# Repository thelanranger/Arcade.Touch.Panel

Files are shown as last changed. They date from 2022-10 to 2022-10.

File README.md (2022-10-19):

# Arcade.Touch.Panel
Capacative Touch Panel using custom PCB and Arduino Leo

int pins are mapped to custom PCB in eagle files. 
Buttons are VCClite capacative touch LCD buttons:
https://vcclite.com/product/csms15cic04/

I specifically used White which did not need SMD resistors and run fine off of USB power (though they are VERY bright).

LEDTimer = 100000;  Can be adjusted to set how long until 'latched' buttons auto off their lights. Example: If you press a button and it is set to 'non latching' the light would blink on touch, but then be in 'always off'. If it was 'latched' (such as mute) the light will remain lit once pressed until it is pressed again OR until LEDTimer ms have passed. Any lights in the 'latched' state would return to their state position on the next button touch.

switch (Bindex) defines the 8 buttons. This sends keystrokes to the system as if the Leonardo was a simple keyboard. The sample file is setup with hotkeys that map to the associated AutoHotKey file to perform the designated actions. 

Example of unlatched press (case 0):
    3 keys are pressed in sequence using Keyboard.press(); then all released using Keyboard.releaseAll();. The light is 'blinked' with a pin write HIGH, delay, and pin write LOW. This sends the sequence of keys then blinks the light. No data is retained and everything is ready for the next loop.

Example of a latched press (case 1):
    lastLEDState[Bindex] is verified. If 'unlatched state' is stored for this button number then we perform the keypress and switch the state from 0 to 1. An immediate exit will allow the cycleLEDs() routine to update turn on the LED and return for the next press. If the reverse is true we can pass the same set of keys again, or an alternate set (in this case we're passing Play [CTRL+SHIFT+G], on latch, then Stop [CTRL+SHIFT+D] on unlatch) and changing the state to off.

This should allow you to perform almost any task! You can even double your buttons with a latching 'shift' button! Just update your .ahk file to match your keystrokes and go nuts.

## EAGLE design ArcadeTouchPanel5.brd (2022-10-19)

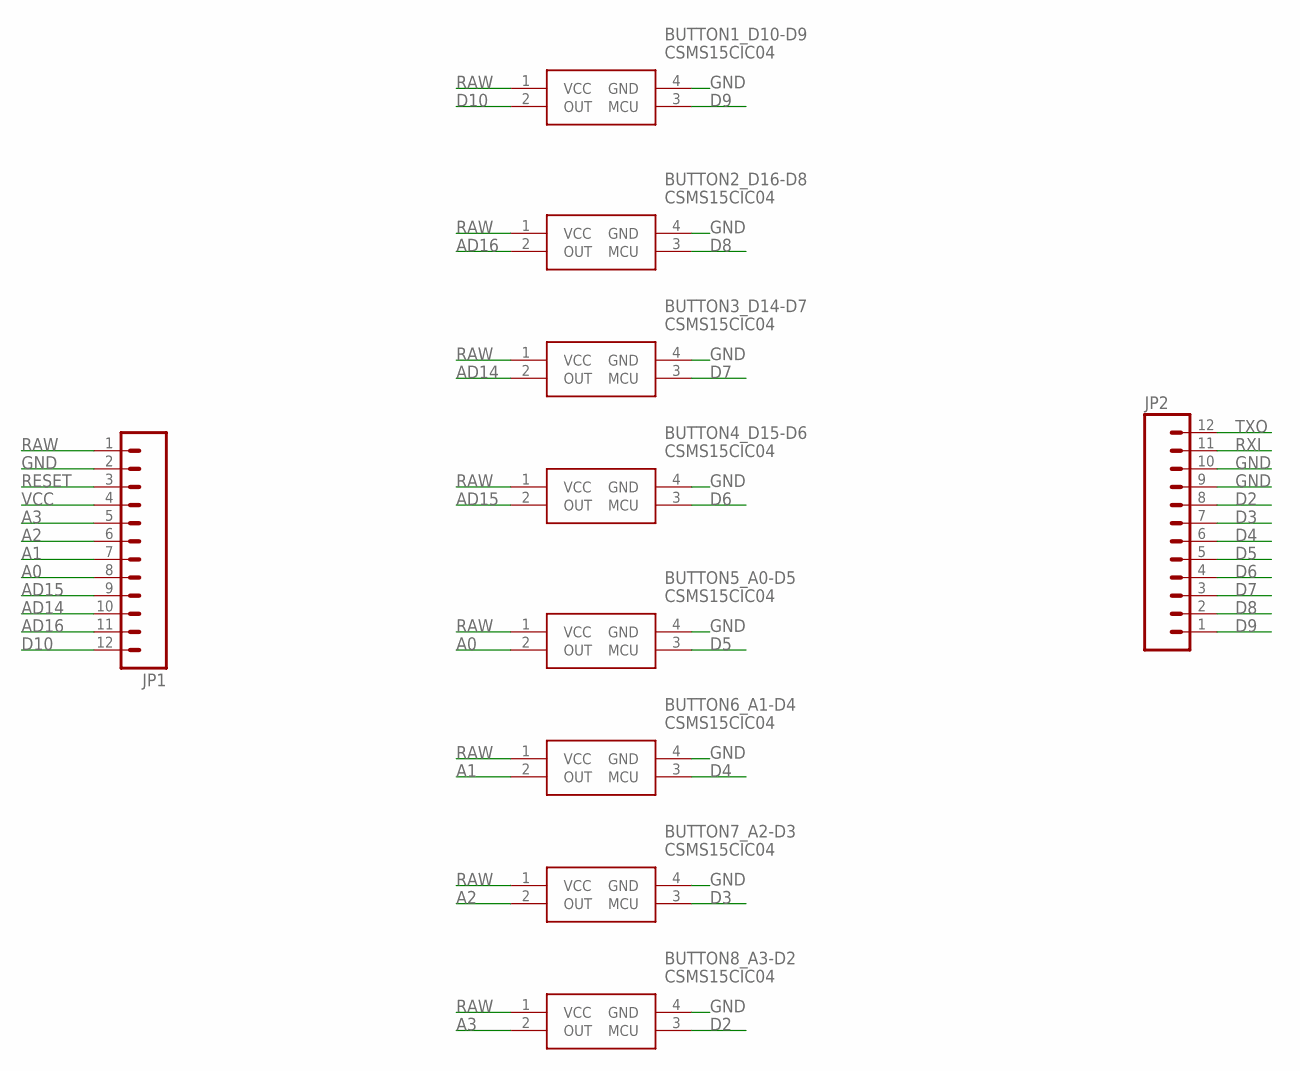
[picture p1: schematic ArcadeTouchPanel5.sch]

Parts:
BUTTON1_D10-D9, BUTTON2_D16-D8, BUTTON3_D14-D7, BUTTON4_D15-D6, BUTTON5_A0-D5, BUTTON6_A1-D4, BUTTON7_A2-D3, BUTTON8_A3-D2: CSMS15CIC04
JP1, JP2: M12PTH; 1X12

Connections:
A0: BUTTON5_A0-D5.2 (OUT), JP1.8
A1: BUTTON6_A1-D4.2 (OUT), JP1.7
A2: BUTTON7_A2-D3.2 (OUT), JP1.6
A3: BUTTON8_A3-D2.2 (OUT), JP1.5
AD14: BUTTON3_D14-D7.2 (OUT), JP1.10
AD15: BUTTON4_D15-D6.2 (OUT), JP1.9
AD16: BUTTON2_D16-D8.2 (OUT), JP1.11
D2: BUTTON8_A3-D2.3 (MCU), JP2.8
D3: BUTTON7_A2-D3.3 (MCU), JP2.7
D4: BUTTON6_A1-D4.3 (MCU), JP2.6
D5: BUTTON5_A0-D5.3 (MCU), JP2.5
D6: BUTTON4_D15-D6.3 (MCU), JP2.4
D7: BUTTON3_D14-D7.3 (MCU), JP2.3
D8: BUTTON2_D16-D8.3 (MCU), JP2.2
D9: BUTTON1_D10-D9.3 (MCU), JP2.1
D10: BUTTON1_D10-D9.2 (OUT), JP1.12
GND: BUTTON1_D10-D9.4 (GND), BUTTON2_D16-D8.4 (GND), BUTTON3_D14-D7.4 (GND), BUTTON4_D15-D6.4 (GND), BUTTON5_A0-D5.4 (GND), BUTTON6_A1-D4.4 (GND), BUTTON7_A2-D3.4 (GND), BUTTON8_A3-D2.4 (GND), JP1.2, JP2.9, JP2.10
RAW: BUTTON1_D10-D9.1 (VCC), BUTTON2_D16-D8.1 (VCC), BUTTON3_D14-D7.1 (VCC), BUTTON4_D15-D6.1 (VCC), BUTTON5_A0-D5.1 (VCC), BUTTON6_A1-D4.1 (VCC), BUTTON7_A2-D3.1 (VCC), BUTTON8_A3-D2.1 (VCC), JP1.1
RESET: JP1.3
RXI: JP2.11
TXO: JP2.12
VCC: JP1.4

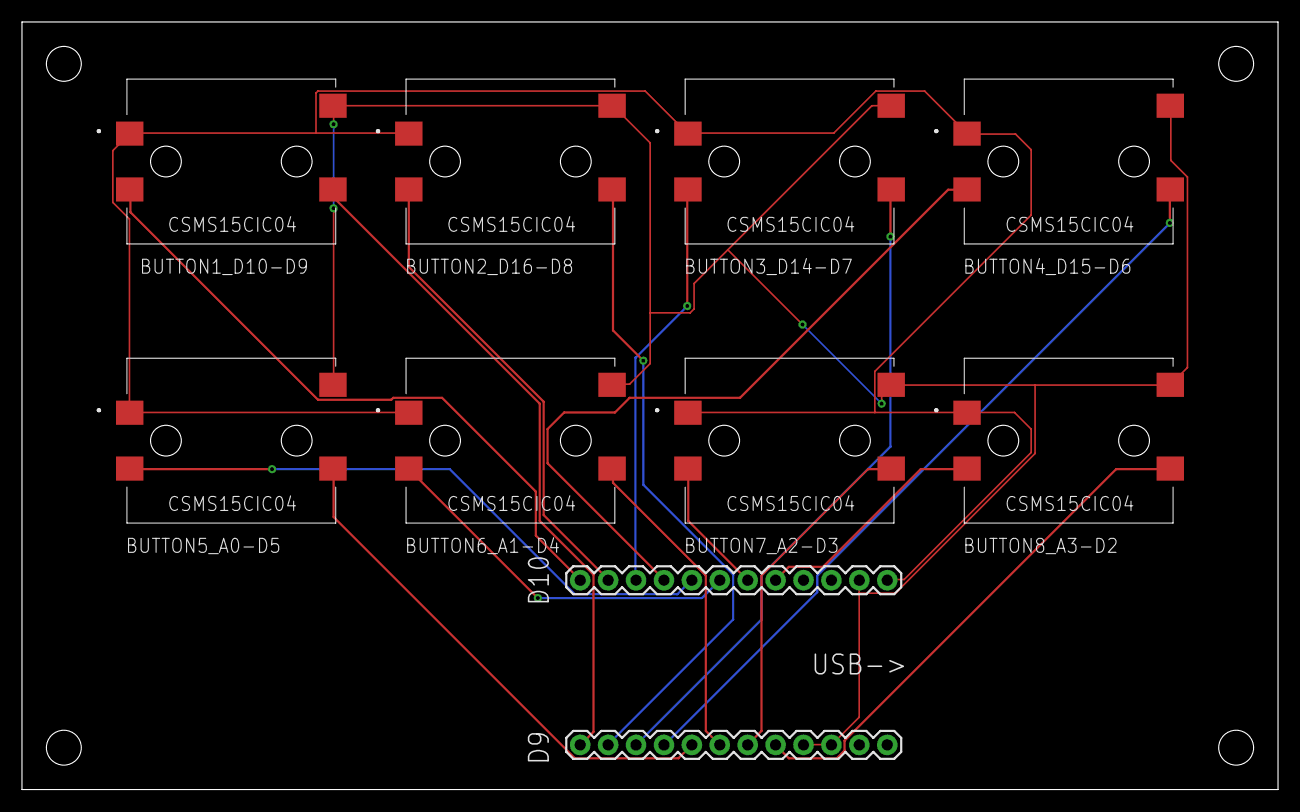
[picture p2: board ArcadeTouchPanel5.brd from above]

Board: 2 copper layers, 114.3 x 69.8 mm, 10 parts (0 on the bottom side), 18 nets.

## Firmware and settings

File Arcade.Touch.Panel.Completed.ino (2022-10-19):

#include "Keyboard.h"

// --Input Pins--
//const int startButton = 18;           //First Button Pin (Digital)
//const int startLED = 8;               //First LED Pin (Digital)
const int totalButtons = 8;             //Total Buttons
const int buttonPins[] = {10, 16, 14, 15, 18, 19, 20, 21};
const int LEDPins[] = {9, 8, 7, 6, 5, 4, 3, 2};
// --Input Pins--

const int Bsmoothing = 50;            // Repeat speed of keys
const int clickDelay = 150;           // Pause Between Clicks
const int long LEDTimer = 100000;           // Time until LEDs Auto Off
int Bsmoothingindex = 0;              // Index of button smoother
int currentButtonState = 0;           // Current Button State
int currentButtonTotal = 0;           // Smoothed State
int long currentLEDState = 0;              // Current LED State
int long currentLEDTime = 0;               // Current LED Time
int lastButtonState[totalButtons][Bsmoothing];    // Last state of the buttons - number of interations
int smoothedButtonState[totalButtons];// Current Button State after smoothing
int lastLEDState[totalButtons];       // Last state of the LEDs

void setup() {
  Serial.begin(9600);

  // --Initialize Button Pins--
  pinMode(0, INPUT_PULLUP); //-- Escape Key!--

  for (int initPinIndex = 0; initPinIndex < totalButtons; initPinIndex++)
  {
    pinMode(buttonPins[initPinIndex], INPUT_PULLUP);
  }
  // --Initialize Button Pins--

  // --Initialize LED Pins--
  for (int initPinIndex = 0; initPinIndex < totalButtons; initPinIndex++)
  {
    pinMode(LEDPins[initPinIndex], OUTPUT);
  }
  // --Initialize Button Pins--

  // --Button Array Init--
  for (int thisReading = 0; thisReading < totalButtons; thisReading++)
  {
    for (int thatReading = 0; thatReading < Bsmoothing; thatReading++)
    {
      lastButtonState[thisReading][thatReading] = 0;
    }
    lastLEDState[thisReading] = 0;
    smoothedButtonState[totalButtons] = 0;
  }
  // --Button Array Init--

  Keyboard.begin();

}

void loop() {
  // --Escape Key!--
  while (digitalRead(0) == LOW)
  {
    Keyboard.releaseAll();
    currentLEDTime = LEDTimer;
    delay(1000);
    Serial.print("Esc State: ");
    Serial.println(digitalRead(0));
  }
  // --Escape Key!--

  buttonPress();
  cycleLEDs();

  // --Read pin values for buttons--
  for (int Bindex = 0; Bindex < totalButtons; Bindex++)
  {
    currentButtonState = digitalRead(buttonPins[Bindex]);
    if (currentButtonState != lastButtonState[Bindex][Bsmoothingindex])
    {
      lastButtonState[Bindex][Bsmoothingindex] = currentButtonState;
    }
  }
  // --Read pin values for buttons--

  Bsmoothingindex++;
  if (Bsmoothingindex > Bsmoothing)
  {
    Bsmoothingindex = 0;
  }
}

void buttonPress()
{
  // --Iterate lastButtonState[][], total, average, populate smoothedButtonState[]--
  for (int Bindex = 0; Bindex < totalButtons; Bindex++)
  {
    currentButtonTotal = 0;

    for (int Sindex = 0; Sindex < Bsmoothing; Sindex++)
    {
      currentButtonTotal = currentButtonTotal + lastButtonState[Bindex][Sindex];
    }

    if ((currentButtonTotal / Bsmoothing) == 0)
    {
      smoothedButtonState[Bindex] = 0;
    }
    else
    {
      smoothedButtonState[Bindex] = 1;
    }
  }
  // --Iterate lastButtonState[][], total, average, populate smoothedButtonState[]--

  // --Iterate smoothedButtonState[], update lastLEDState[], send Keyboard.Press()--
  for (int Bindex = 0; Bindex < totalButtons; Bindex++)
  {
    if (smoothedButtonState[Bindex] == 1)
    {
      smoothedButtonState[Bindex] = 0;
      currentLEDTime = 0;                   //  Auto LED Off reset
      for (int Rindex = 0; Rindex < Bsmoothing; Rindex++)
      {
        lastButtonState[Bindex][Rindex] = 0;
      }
      switch (Bindex) {
        case 0:     // Winamp Previous  (CTRL+SHIFT+A)
          Keyboard.press(KEY_LEFT_CTRL);
          Keyboard.press(KEY_LEFT_SHIFT);
          Keyboard.press('A');
          Keyboard.releaseAll();
          digitalWrite(LEDPins[Bindex], HIGH);
          delay(clickDelay);
          digitalWrite(LEDPins[Bindex], LOW);
          delay(clickDelay);
          break;
        case 1:     // Winamp Play/Pause/Stop  (CTRL+SHIFT+G)/(CTRL+SHIFT+H)/(CTRL+SHIFT+D)
          if (lastLEDState[Bindex] == 0)
          {
            lastLEDState[Bindex] = 1;
            Keyboard.press(KEY_LEFT_CTRL);
            Keyboard.press(KEY_LEFT_SHIFT);
            Keyboard.press('G');
            Keyboard.releaseAll();
            //digitalWrite(LEDPins[Bindex], HIGH);
            delay(clickDelay);
            break;
          }
          if (lastLEDState[Bindex] == 1)
          {
            lastLEDState[Bindex] = 0;
            Keyboard.press(KEY_LEFT_CTRL);
            Keyboard.press(KEY_LEFT_SHIFT);
            Keyboard.press('D');
            Keyboard.releaseAll();
            //digitalWrite(LEDPins[Bindex], LOW);
            delay(clickDelay);
            break;
          }
          break;
        case 2:     // Winamp Next  (CTRL+SHIFT+F)
          Keyboard.press(KEY_LEFT_CTRL);
          Keyboard.press(KEY_LEFT_SHIFT);
          Keyboard.press('F');
          Keyboard.releaseAll();
          digitalWrite(LEDPins[Bindex], HIGH);
          delay(clickDelay);
          digitalWrite(LEDPins[Bindex], LOW);
          delay(clickDelay);
          break;
        case 3:     // Pending | Pause (P)
          //Keyboard.press(KEY_LEFT_CTRL);
          //Keyboard.press(KEY_LEFT_SHIFT);
          Keyboard.press('P');
          Keyboard.releaseAll();
          digitalWrite(LEDPins[Bindex], HIGH);
          delay(clickDelay);
          digitalWrite(LEDPins[Bindex], LOW);
          delay(clickDelay);
          break;
        case 4:     // Volume Down  (CTRL+SHIFT+-)
          Keyboard.press(KEY_LEFT_CTRL);
          Keyboard.press(KEY_LEFT_SHIFT);
          Keyboard.press('-');
          Keyboard.releaseAll();
          digitalWrite(LEDPins[Bindex], HIGH);
          delay(clickDelay);
          digitalWrite(LEDPins[Bindex], LOW);
          delay(clickDelay);
          break;
        case 5:     // Volume Up  (CTRL+SHIFT+=)
          delay(clickDelay);
          Keyboard.press(KEY_LEFT_CTRL);
          Keyboard.press(KEY_LEFT_SHIFT);
          Keyboard.press('=');
          Keyboard.releaseAll();
          digitalWrite(LEDPins[Bindex], HIGH);
          delay(clickDelay);
          digitalWrite(LEDPins[Bindex], LOW);
          delay(clickDelay);
          break;
        case 6:     // Mute      (CTRL+SHIFT+M)/(CTRL+SHIFT+N)
          delay(clickDelay);
          if (lastLEDState[Bindex] == 0) {
            lastLEDState[Bindex] = 1;
            Keyboard.press(KEY_LEFT_CTRL);
            Keyboard.press(KEY_LEFT_SHIFT);
            Keyboard.press('M');
            Keyboard.releaseAll();
            delay(clickDelay);
            break;
          }
          if (lastLEDState[Bindex] == 1) {
            lastLEDState[Bindex] = 0;
            Keyboard.press(KEY_LEFT_CTRL);
            Keyboard.press(KEY_LEFT_SHIFT);
            Keyboard.press('N');
            Keyboard.releaseAll();
            delay(clickDelay);
            break;
          }
          break;
        case 7:     // Pending  (Pause) (P)
          delay(clickDelay);
          //Keyboard.press(KEY_LEFT_CTRL);
          //Keyboard.press(KEY_LEFT_SHIFT);
          Keyboard.press('P');
          Keyboard.releaseAll();
          digitalWrite(LEDPins[Bindex], HIGH);
          delay(clickDelay);
          digitalWrite(LEDPins[Bindex], LOW);
          delay(clickDelay);
          break;
      }
    }
    // --Iterate smoothedButtonState[], update lastLEDState[], send Keyboard.Press()--
  }


}


void cycleLEDs()
{
  // --Auto Off All LEDs
  currentLEDTime = currentLEDTime + 1;
  Serial.print("LED Timer: ");
  Serial.println(currentLEDTime);
  Serial.println(LEDTimer);

  if (currentLEDTime > LEDTimer)
  {
    for (int Tindex = 0; Tindex < totalButtons; Tindex++)
    {
      digitalWrite(LEDPins[Tindex], LOW);
    }
    return;
  }
  // --Auto Off All LEDs

  else {
    // --Set LED Status for All--
    for (int Lindex = 0; Lindex < totalButtons; Lindex++) {
      currentLEDState = digitalRead(LEDPins[Lindex]);
      if (currentLEDState != lastLEDState[Lindex]) {
        if (lastLEDState[Lindex] == 0) {
          digitalWrite(LEDPins[Lindex], LOW);
        }
        if (lastLEDState[Lindex] == 1) {
          digitalWrite(LEDPins[Lindex], HIGH);
        }
      }
      //Serial.print("LED State: ");
      //Serial.println(lastLEDState[Lindex]);
    }
    // --Set LED Status for All--
  }
}

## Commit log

2022-10-19 Add files via upload
    Eagle Files for board.
    [ArcadeTouchPanel5.brd, ArcadeTouchPanel5.sch]
2022-10-19 Add files via upload
    CNC files to send for complete board
